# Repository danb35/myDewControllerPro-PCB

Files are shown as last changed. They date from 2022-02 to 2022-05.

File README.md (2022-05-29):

# myDewControllerPro-PCB
KiCad schematic and board for myDewControllerPro: https://sourceforge.net/projects/arduinonanodewcontrollerpro/

# Introduction
myFocuserPro is a DIY, Arduino-based dew heater controller designed for use with telescopes.  The design, source code, schematics, PCB files (Gerbers), and extensive documentation are available at the link above.  So what am I doing in this repo?

Unfortunately, the Gerbers there have a few issues, most notably that the footprint for the reverse-polarity protection diode (D1 on the schematic) just doesn't fit the specified diode.  The specified "fix" for the problem is to file down the leads of the diode until they fit through the holes.  And while this should be a trivial thing to fix, editable source files for the schematic and board haven't been released.

To address this, I re-drew the schematic and PCB layout in KiCad 6.0.  [KiCad](https://www.kicad.org/) is free, open source electronics design software, so you can download it to edit these files as desired.

# Design changes
This schematic is identical to the schematic at SourceForge.  I intend (and hope) that the schematic will be easier to read and follow, but there should not be any changes in the components or how they're connected.  Most of the reference designators (i.e., R3, C2, etc.) are identical, but KiCad has changed some of the semiconductors.  I have, however, made a few changes to the board layout.

First, of course, there's the change that drove the whole redesign--the footprint for D1 now actually fits the specified diode.  I've also replaced most of the places where pin headers had been used for off-board connections (e.g., for the pushbuttons, the display, etc.) with JST-XH connectors.  These provide some friction to prevent connections from coming loose inadvertently, and also polarize the connections (so, e.g., you can't plug in a LED backward).

# Bill of Materials
The bill of materials is not appreciably different from the upstream project, but it's now included in this repo, both as an OpenDocument Spreadsheet file and as a PDF.

# Enclosure
While the board size is similar to the original, it is not identical, and it will not fit in the 3D-printed case design that's posted on SourceForge.  I've designed an enclosure that will fit this board; STLs and STEP files are in the `Enclosure` directory.

# Board Images
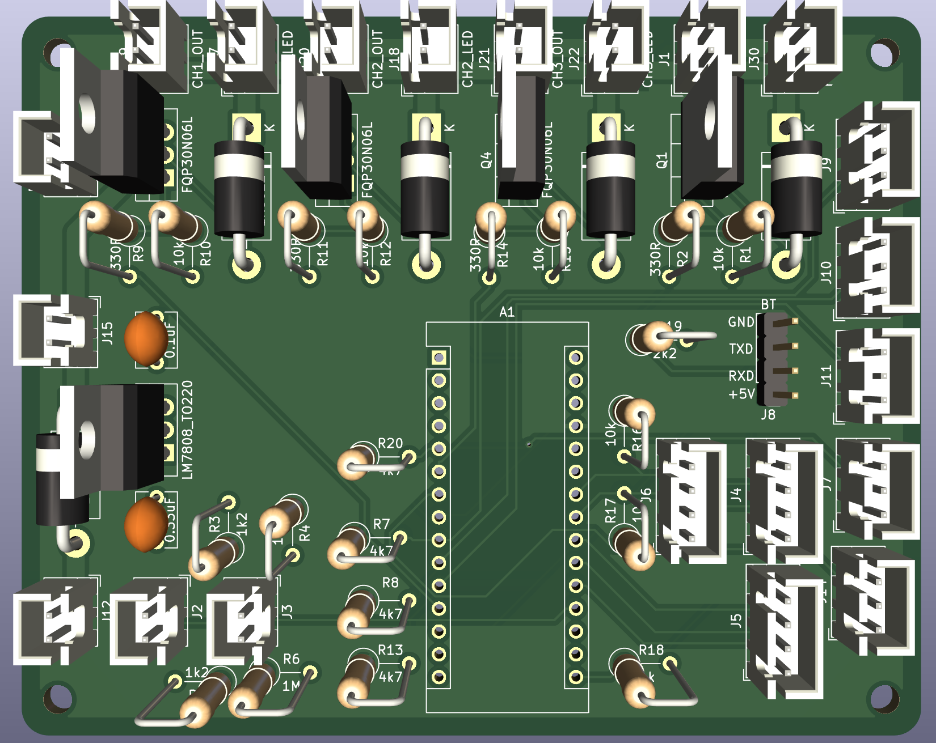
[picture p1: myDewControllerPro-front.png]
Front PCB image

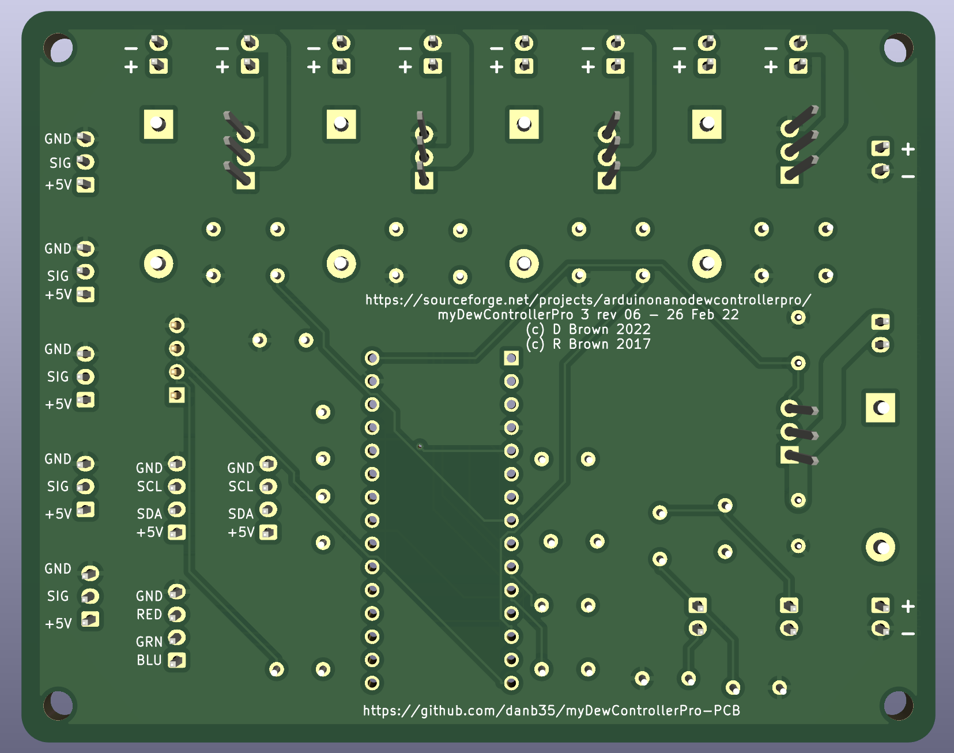
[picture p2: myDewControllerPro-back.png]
Back PCB Image


# Ordering
I don't sell these boards; you can have them made by any PCB fab you choose.  To do so, simply download Gerber/myDewControllerPro.zip from this repo, upload it to your fab of choice, and have at it.  If you don't have a fab of choice, consider the two linked below, in which I have no financial interest (i.e., I'm not an affiliate, partner, or anything else; I don't make anything from your purchase of these boards--I'm just a customer of both services).

To order from JLCPCB, or most other PCB fabs, download the .zip file from the `Gerbers` directory.  You can then upload it to your preferred vendor to price and order your PCBs.

## OSHPark
OSHPark are an American company known for high-quality boards.  They'll produce three copies of your design for $5 per square inch, in purple, with gold plating.  This cost is often higher than the Chinese fabs, but they don't charge shipping, and you don't have to wait for shipping for China.  This board costs about $62 shipped for three copies as of this writing.  You can order boards using this link:
https://oshpark.com/profiles/danb35

## JLCPCB
[JLCPCB](https://jlcpcb.com/) are a Chinese PCB fab that I've been pretty happy with.  Their prices are low (starting at $2/5 boards), they produce the boards quickly, and they ship quickly via DHL.  The biggest drawback is the cost of shipping--at this writing, five boards will cost you $2, but the shipping is another $20 or more.

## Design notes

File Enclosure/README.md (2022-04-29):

# Enclosure Design
Included in this directory are STLs and editable CAD (STEP) files for an enclosure and lid for the PCB design in this repo.  The lid has an opening for a 1.3" OLED display, and for LEDs for power and three output channels.  The back panel has connections for power, three output channels, and temperature sensors for those three channels.  The ambient temperature/humidity sensor (I'm using a [AM2301 module](https://www.ebay.com/itm/191464821805), compatible with the DHT21) mounts to the right side of the enclosure using a M3 screw, and the wires feed through the slot in that side.  The lid fastens with M3 screws, and recesses on the bottom are for M3 heat-set inserts, which I used to fasten the enclosure to a Vixen dovetail clamp.

This design calls for GX12-2 and GX12-3 connectors for power and the temperature sensors, and RCA connectors for the heat bands themselves.

I printed this in PLA with 0.2 mm layer height with Cura's standard settings (two walls, 20% infill).  Filament and print settings are at your discretion; this piece shouldn't call for much in the way of strucural integrity.

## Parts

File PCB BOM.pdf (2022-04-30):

Sheet1

Page 1

# Bill of Materials

## PCB-mounted components

Ref | Qty | Value | Description | Source
A1 | 1 | Arduino Nano v3.x
C1 | 1 | 0.33 uF | Ceramic Capacitor
C2 | 1 | 0.1 uF | Ceramic Capacitor
D1, D3, D4, D5 | 4 | 1N5822 | Diode
D2 | 1 | 10A10 | Diode
| 13 | 2-pin | JST-XH PCB-mount male connector
J4, J5, J6, J8 | 4 | 4-pin | JST-XH PCB-mount male connector
J9-J11, J14 | 4 | 3-pin | JST-XH PCB-mount male connector
Q1, Q2, Q3, Q4 | 4 | FQP30N06L
6 | 10k | Resistor
4 | 330R | Resistor
R3, R4, R5 | 3 | 1k2 | Resistor
R6 | 1 | 1M | Resistor
4 | 4k7 | Resistor
R18 | 1 | 1k | Resistor
R19 | 1 | 2k2 | Resistor
U1 | 1 | LM7808

## Additional Components

| 1
| 3

J1, J2, J3, J12,
J15-J22, J30

30A Id, 50V Vds, N-Channel Power MOSFET, TO-220
R1, R10, R12,
R15, R16, R17
R2, R9, R11,
R14

R7, R8, R13,
R20

Positive 1A 35V Linear Regulator, Fixed Output 8V, TO-220

GX12-2 panel-mount male connector w/
matching female connector, power in | https://www.amazon.com/gp/product/B089YT6LFN
GX12-3 panel-mount male connector w/
matching female connector, temp sensors | https://www.amazon.com/gp/product/B06XRT2YFV

Sheet1

Page 2

3 | RCA Female panel-mount connectors
3 | Waterproof DS18B20 temperature sensors
5 | 12-volt LEDs for power and heater status

1
1 | 1.3” 128x64 OLED display
JST-XH female connectors and pins as needed https://www.amazon.com/gp/product/B07SS7JDLNhttps://www.amazon.com/gp/product/B012C597T0https://www.amazon.com/dp/B07M9YT8C8Temp/humidity sensor module: DHT11/21,
HTU21D, AM2301 | https://www.ebay.com/itm/191464821805
https://www.ebay.com/itm/391731053045

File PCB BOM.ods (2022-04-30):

Bill of Materials
PCB-mounted components
Ref | Qty | Value | Description | Source
A1 | 1 |  | Arduino Nano v3.x
C1 | 1 | 0.33 uF | Ceramic Capacitor
C2 | 1 | 0.1 uF | Ceramic Capacitor
D1, D3, D4, D5 | 4 | 1N5822 | Diode
D2 | 1 | 10A10 | Diode
J1, J2, J3, J12, J15-J22, J30 | 13 | 2-pin | JST-XH PCB-mount male connector
J4, J5, J6, J8 | 4 | 4-pin | JST-XH PCB-mount male connector
J9-J11, J14 | 4 | 3-pin | JST-XH PCB-mount male connector
Q1, Q2, Q3, Q4 | 4 | FQP30N06L | 30A Id, 50V Vds, N-Channel Power MOSFET, TO-220
R1, R10, R12, R15, R16, R17 | 6 | 10k | Resistor
R2, R9, R11, R14 | 4 | 330R | Resistor
R3, R4, R5 | 3 | 1k2 | Resistor
R6 | 1 | 1M | Resistor
R7, R8, R13, R20 | 4 | 4k7 | Resistor
R18 | 1 | 1k | Resistor
R19 | 1 | 2k2 | Resistor
U1 | 1 | LM7808 | Positive 1A 35V Linear Regulator, Fixed Output 8V, TO-220
Additional Components
 | 1 |  | GX12-2 panel-mount male connector w/ matching female connector, power in | https://www.amazon.com/gp/product/B089YT6LFN
 | 3 |  | GX12-3 panel-mount male connector w/ matching female connector, temp sensors | https://www.amazon.com/gp/product/B06XRT2YFV
 | 3 |  | RCA Female panel-mount connectors | https://www.amazon.com/gp/product/B07SS7JDLN
 | 3 |  | Waterproof DS18B20 temperature sensors | https://www.amazon.com/gp/product/B012C597T0
 | 5 |  | 12-volt LEDs for power and heater status | https://www.amazon.com/dp/B07M9YT8C8
 | 1 |  | Temp/humidity sensor module: DHT11/21, HTU21D, AM2301 | https://www.ebay.com/itm/191464821805
 | 1 |  | 1.3” 128x64 OLED display | https://www.ebay.com/itm/391731053045
 |  |  | JST-XH female connectors and pins as needed

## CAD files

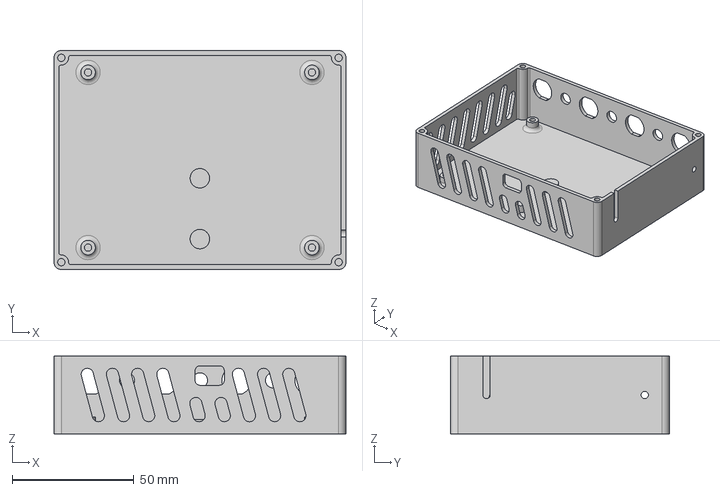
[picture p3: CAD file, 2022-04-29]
Enclosure/myDewControllerPro Enclosure.step
120.0 x 90.0 x 32.0 mm

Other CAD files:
Enclosure/myDewControllerPro Enclosure.stl

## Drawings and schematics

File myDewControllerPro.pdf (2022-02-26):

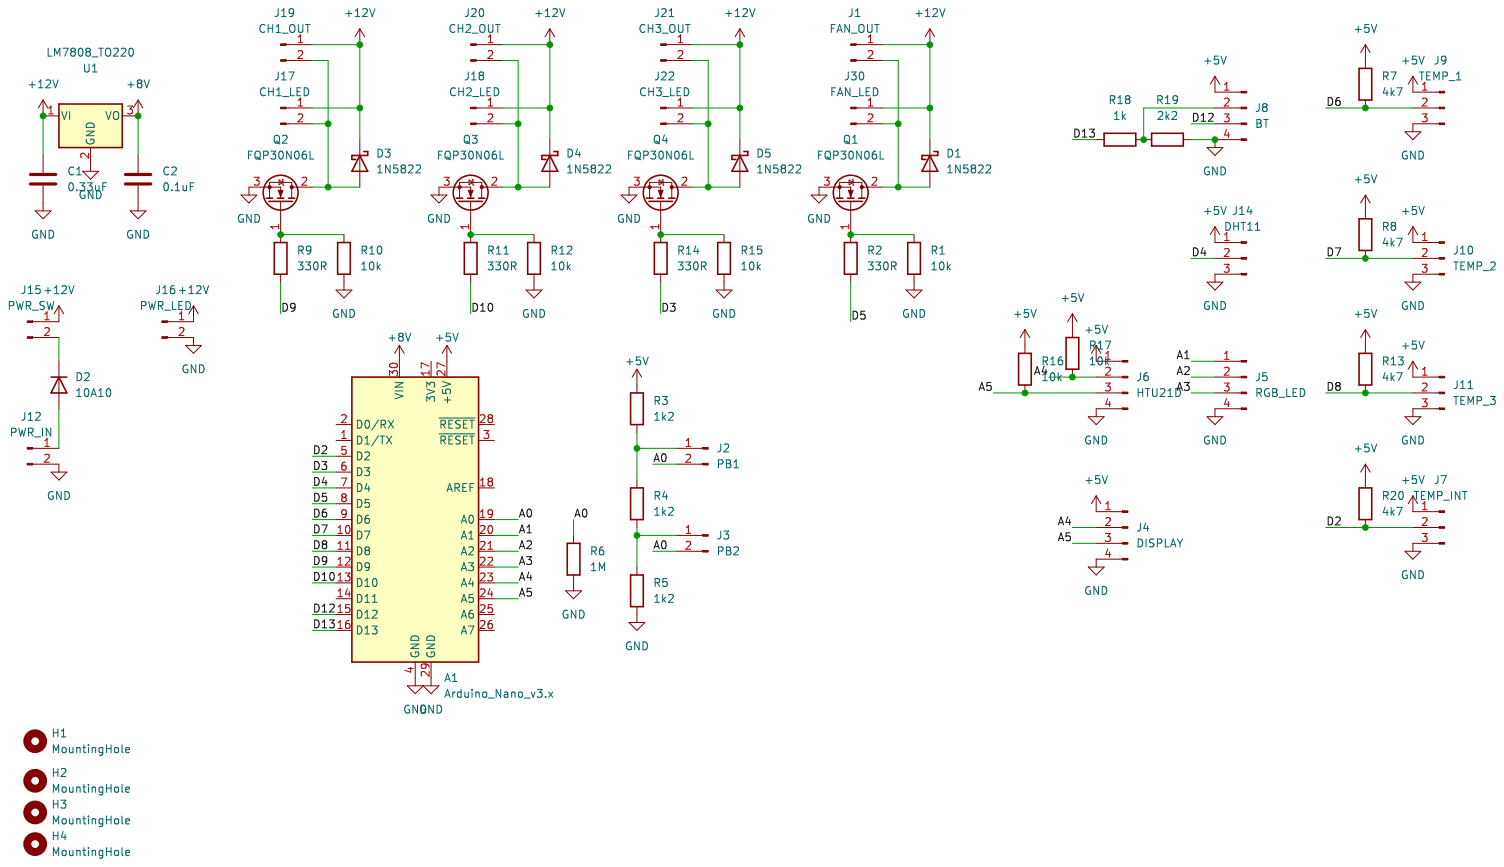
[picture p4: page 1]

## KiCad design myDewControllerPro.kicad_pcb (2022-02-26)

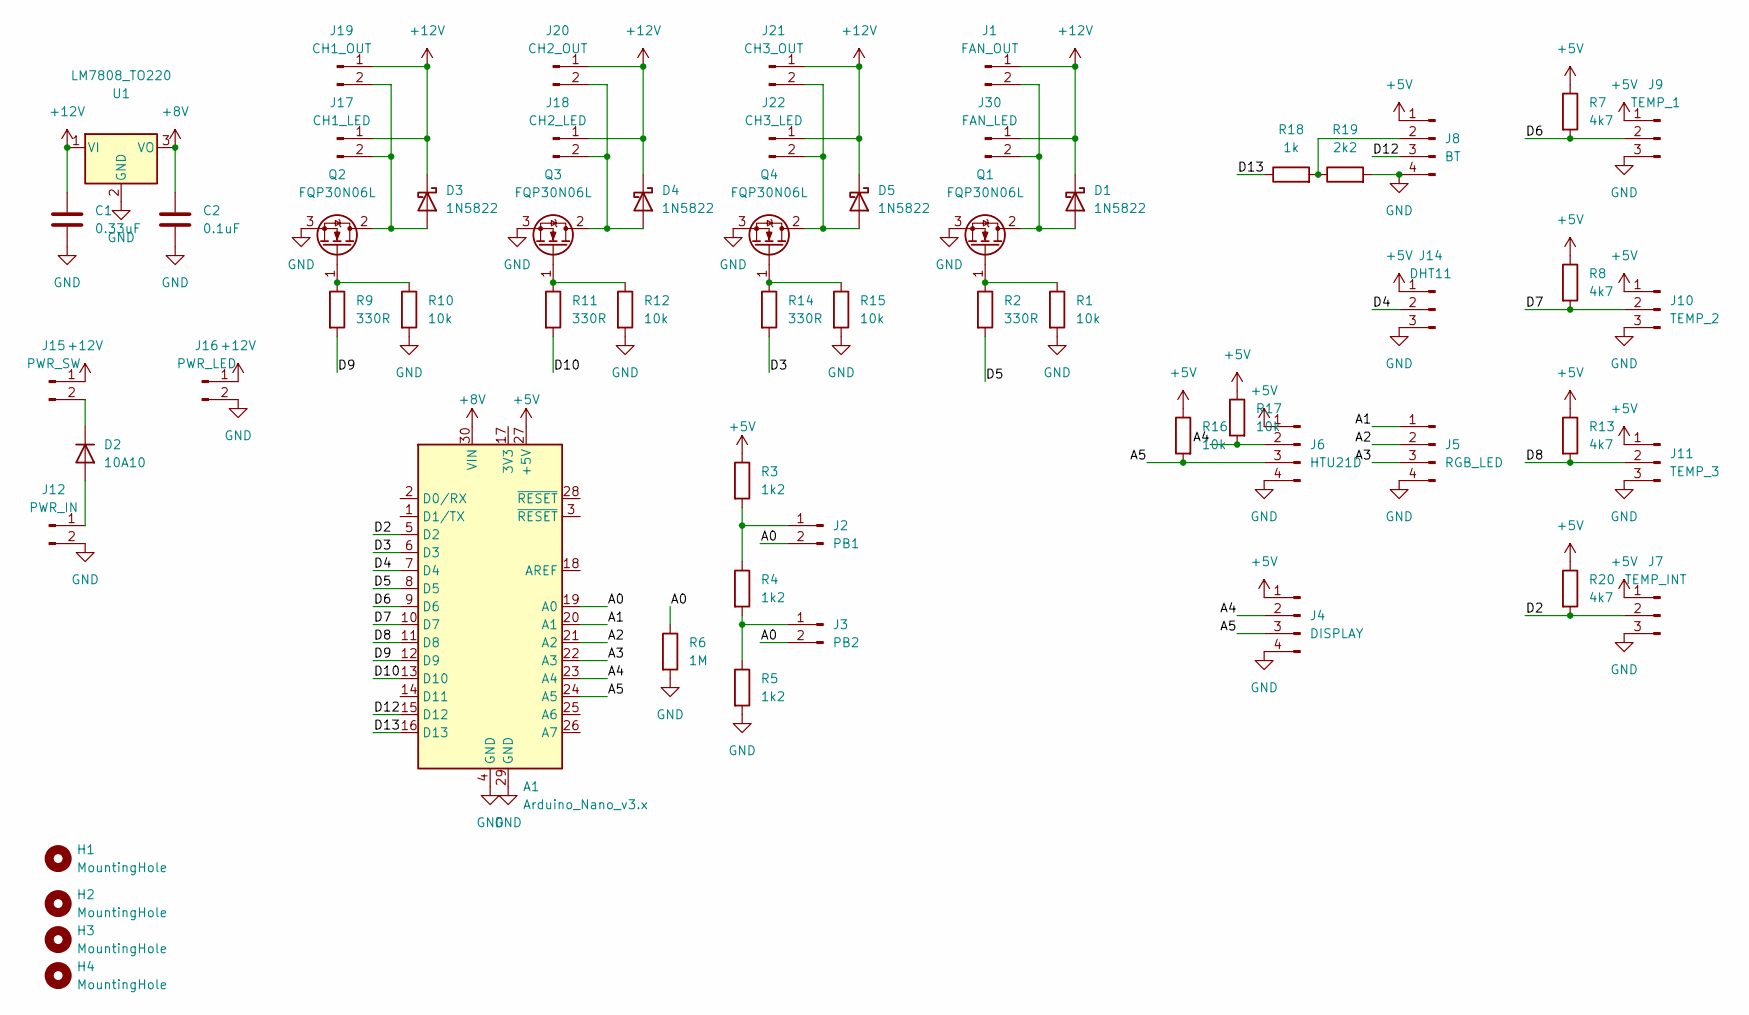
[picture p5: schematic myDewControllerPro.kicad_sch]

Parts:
A1: Arduino_Nano_v3.x; Arduino_Nano
C1: 0.33uF; C_Disc_D6.0mm_W4.4mm_P5.00mm
C2: 0.1uF; C_Disc_D6.0mm_W4.4mm_P5.00mm
D1, D3, D4, D5: 1N5822; D_DO-201AD_P15.24mm_Horizontal
D2: 10A10
H1, H2, H3, H4: MountingHole; MountingHole_3.2mm_M3
J1: FAN_OUT; JST_XH_B2B-XH-A_1x02_P2.50mm_Vertical
J2: PB1; JST_XH_B2B-XH-A_1x02_P2.50mm_Vertical
J3: PB2; JST_XH_B2B-XH-A_1x02_P2.50mm_Vertical
J4: DISPLAY; JST_XH_B4B-XH-A_1x04_P2.50mm_Vertical
J5: RGB_LED; JST_XH_B4B-XH-A_1x04_P2.50mm_Vertical
J6: HTU21D; JST_XH_B4B-XH-A_1x04_P2.50mm_Vertical
J7: TEMP_INT; JST_XH_B3B-XH-A_1x03_P2.50mm_Vertical
J8: BT; PinHeader_1x04_P2.54mm_Vertical
J9: TEMP_1; JST_XH_B3B-XH-A_1x03_P2.50mm_Vertical
J10: TEMP_2; JST_XH_B3B-XH-A_1x03_P2.50mm_Vertical
J11: TEMP_3; JST_XH_B3B-XH-A_1x03_P2.50mm_Vertical
J12: PWR_IN; JST_XH_B2B-XH-A_1x02_P2.50mm_Vertical
J14: DHT11; JST_XH_B3B-XH-AM_1x03_P2.50mm_Vertical
J15: PWR_SW; JST_XH_B2B-XH-A_1x02_P2.50mm_Vertical
J16: PWR_LED; JST_XH_B2B-XH-A_1x02_P2.50mm_Vertical
J17: CH1_LED; JST_XH_B2B-XH-A_1x02_P2.50mm_Vertical
J18: CH2_LED; JST_XH_B2B-XH-A_1x02_P2.50mm_Vertical
J19: CH1_OUT; JST_XH_B2B-XH-A_1x02_P2.50mm_Vertical
J20: CH2_OUT; JST_XH_B2B-XH-A_1x02_P2.50mm_Vertical
J21: CH3_OUT; JST_XH_B2B-XH-A_1x02_P2.50mm_Vertical
J22: CH3_LED; JST_XH_B2B-XH-A_1x02_P2.50mm_Vertical
J30: FAN_LED; JST_XH_B2B-XH-A_1x02_P2.50mm_Vertical
Q1, Q2, Q3, Q4: FQP30N06L; TO-220-3_Vertical
R1, R10, R12, R15, R16, R17: 10k; R_Axial_DIN0309_L9.0mm_D3.2mm_P5.08mm_Vertical
R2, R9, R11, R14: 330R; R_Axial_DIN0309_L9.0mm_D3.2mm_P5.08mm_Vertical
R3, R4, R5: 1k2; R_Axial_DIN0309_L9.0mm_D3.2mm_P5.08mm_Vertical
R6: 1M; R_Axial_DIN0309_L9.0mm_D3.2mm_P5.08mm_Vertical
R7, R8, R13, R20: 4k7; R_Axial_DIN0309_L9.0mm_D3.2mm_P5.08mm_Vertical
R18: 1k; R_Axial_DIN0309_L9.0mm_D3.2mm_P5.08mm_Vertical
R19: 2k2; R_Axial_DIN0309_L9.0mm_D3.2mm_P5.08mm_Vertical
U1: LM7808_TO220; TO-220-3_Vertical

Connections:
+5V: A1.27 (+5V), J4.1, J6.1, J7.1, J8.1, J9.1, J10.1, J11.1, J14.1, R3.1, R7.1, R8.1, R13.1, R16.1, R17.1, R20.1
+8V: A1.30 (VIN), C2.1, U1.3 (VO)
+12V: C1.1, D1.1 (K), D3.1 (K), D4.1 (K), D5.1 (K), J1.1, J15.1, J16.1, J17.1, J18.1, J19.1, J20.1, J21.1, J22.1, J30.1, U1.1 (VI)
/A0: A1.19 (A0), J2.2, J3.2, R6.1
/A1: A1.20 (A1), J5.1
/A2: A1.21 (A2), J5.2
/A3: A1.22 (A3), J5.3
/A4: A1.23 (A4), J4.2, J6.2, R17.2
/A5: A1.24 (A5), J4.3, J6.3, R16.2
/D2: A1.5 (D2), J7.2, R20.2
/D3: A1.6 (D3), R14.2
/D4: A1.7 (D4), J14.2
/D5: A1.8 (D5), R2.2
/D6: A1.9 (D6), J9.2, R7.2
/D7: A1.10 (D7), J10.2, R8.2
/D8: A1.11 (D8), J11.2, R13.2
/D9: A1.12 (D9), R9.2
/D10: A1.13 (D10), R11.2
/D12: A1.15 (D12), J8.3
/D13: A1.16 (D13), R18.1
GND: A1.4 (GND), A1.29 (GND), C1.2, C2.2, J4.4, J5.4, J6.4, J7.3, J8.4, J9.3, J10.3, J11.3, J12.2, J14.3, J16.2, Q1.3 (S), Q2.3 (S), Q3.3 (S), Q4.3 (S), R1.2, R5.2, R6.2, R10.2, R12.2, R15.2, R19.2, U1.2 (GND)
unnamed: D1.2 (A), J1.2, J30.2, Q1.2 (D)
unnamed: D2.1 (K), J15.2
unnamed: D2.2 (A), J12.1
unnamed: D3.2 (A), J17.2, J19.2, Q2.2 (D)
unnamed: D4.2 (A), J18.2, J20.2, Q3.2 (D)
unnamed: D5.2 (A), J21.2, J22.2, Q4.2 (D)
unnamed: J2.1, R3.2, R4.1
unnamed: J3.1, R4.2, R5.1
unnamed: J8.2, R18.2, R19.1
unnamed: Q1.1 (G), R1.1, R2.1
unnamed: Q2.1 (G), R9.1, R10.1
unnamed: Q3.1 (G), R11.1, R12.1
unnamed: Q4.1 (G), R14.1, R15.1

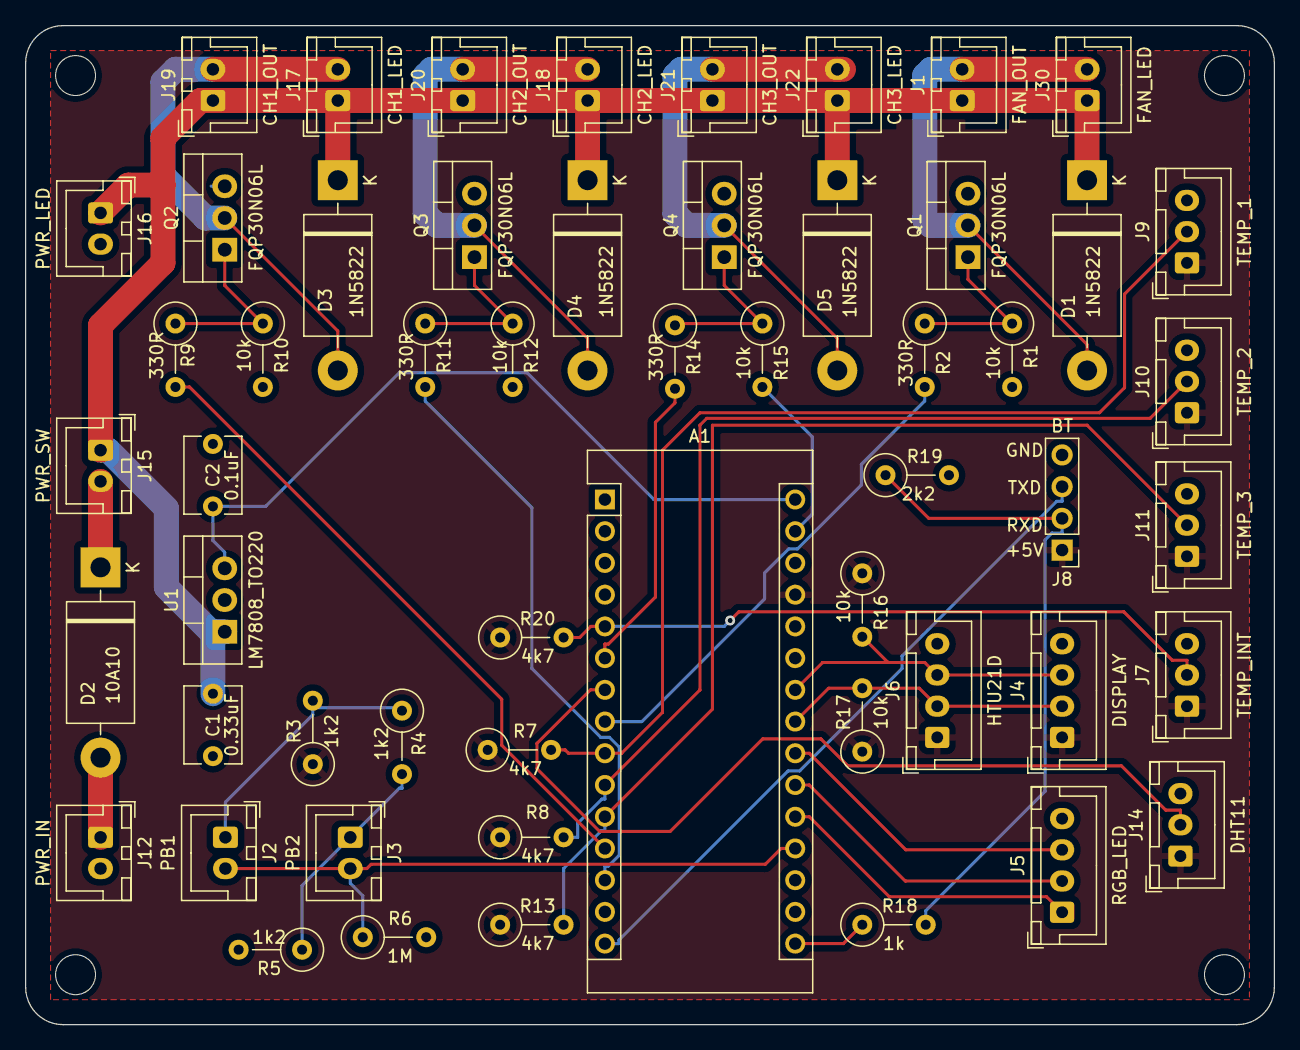
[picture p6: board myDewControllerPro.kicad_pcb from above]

Board: 2 copper layers, 100.0 x 80.0 mm, 59 parts (0 on the bottom side), 34 nets.

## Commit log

2022-04-29 Add enclosure
    [myDewControllerPro Enclosure.step, myDewControllerPro Enclosure.stl]
2022-04-29 Add BOM
    [PCB BOM.ods]
2022-04-30 Update BOM
    PDF now in landscape
    [PCB BOM.ods]
